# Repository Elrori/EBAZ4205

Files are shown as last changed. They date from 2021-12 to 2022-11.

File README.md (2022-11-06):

# EBAZ4205

EBIT EBAZ4205 ZYNQ7Z010 BOARD.

EBAZ4205是EBIT BTC矿机的控制板，是最便宜的矿板，其他还有EBAZ4203等。EBAZ4205板载一块Xilinx ZYNQ7Z010 SOC、256MB DDR3内存、一块128MB NAND和100M以太网PHY等。原理图和PCB从二手商获得。默认情况下，板子需要从2.0mm的PHD排针供电，电压5V-12V。Linux默认从NAND启动并执行挖矿控制程序。板子有SD卡接口，可以自己焊接SD卡接口，并更改电阻，使ZYNQ从SD启动。板子价格便宜适合用于学习ZYNQ。但是，比较遗憾的是ZYNQ的USB引脚并未引出。

- 裸机程序固化方法(原始板子)

  文章[链接](https://www.jianshu.com/p/b83c663ecaaa)

- u-boot&Linux生成方法记录(SD卡启动)

  文章[链接](https://www.jianshu.com/p/370f95f0068f)

- EBAZ4205+HDMI视频软解测试(SD卡启动)

  文章[链接](https://www.jianshu.com/p/f035751c2fe5)

- EBAZ420x OpenWrt Release.

  [Elrori/openwrt-auto](https://github.com/Elrori/openwrt-auto)
  
  [将EBAZ4205变为OpenWrt旁路由](https://blog.csdn.net/z951573431/article/details/123819564)

- 其他资料

  [其他关联repo(en)](https://github.com/xjtuecho/EBAZ4205)
  
  [EBIT S9原理图](https://github.com/openzynqhardware/ebaz4205-openwrt/tree/master/hardware/S9)

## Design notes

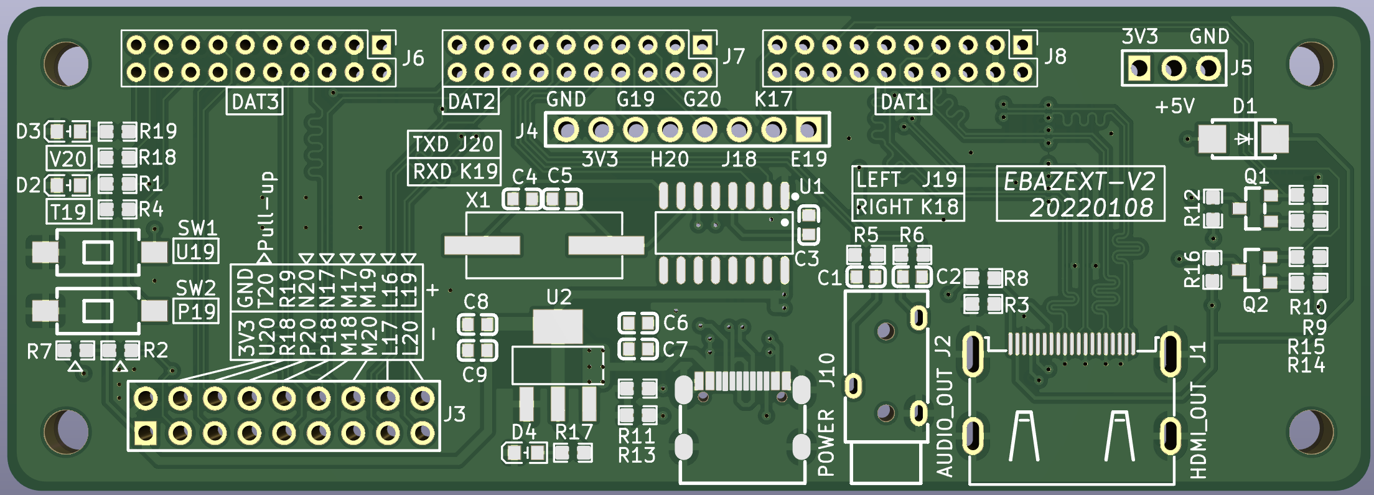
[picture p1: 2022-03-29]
EBAZEXT-V2/ebazext-v2.png

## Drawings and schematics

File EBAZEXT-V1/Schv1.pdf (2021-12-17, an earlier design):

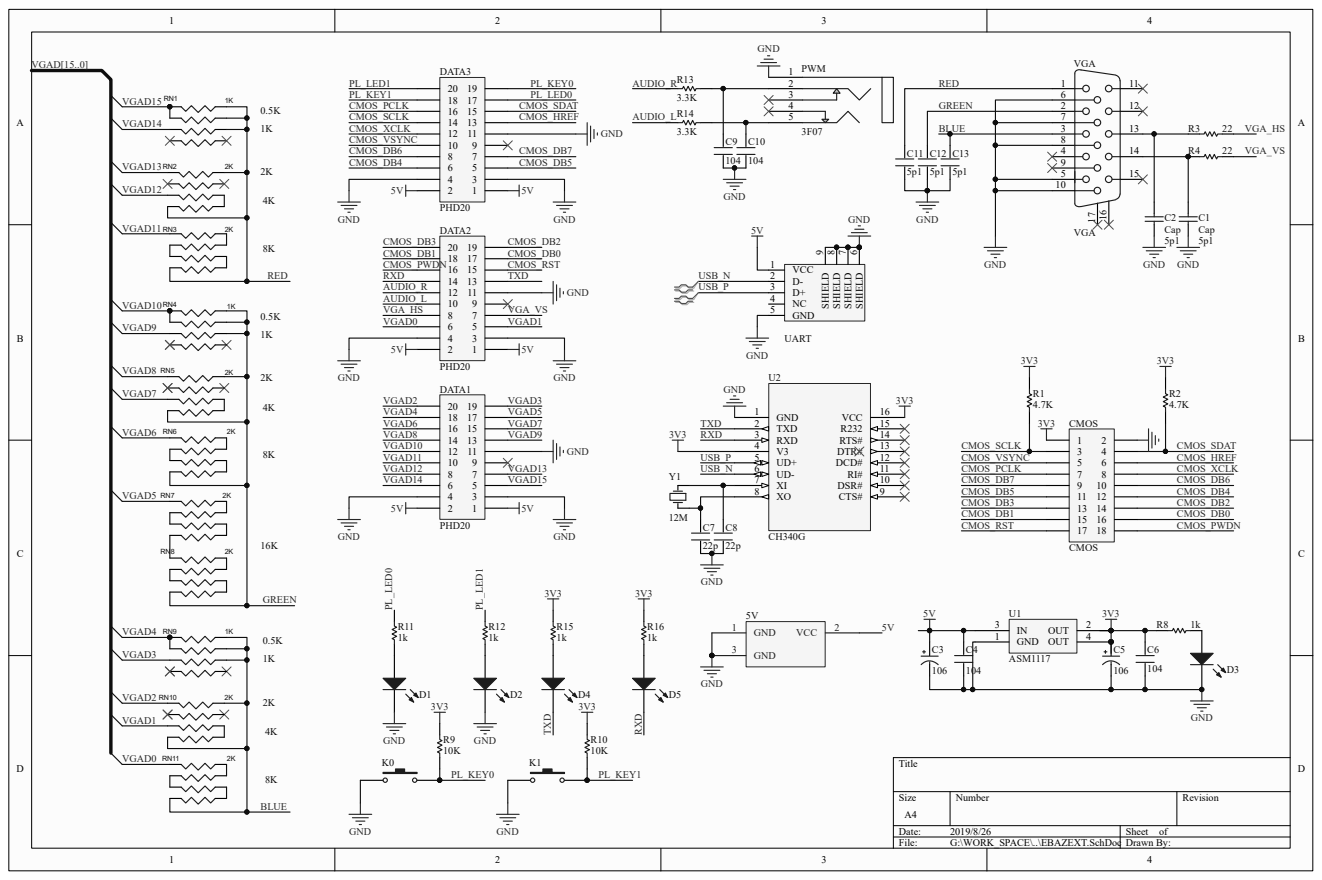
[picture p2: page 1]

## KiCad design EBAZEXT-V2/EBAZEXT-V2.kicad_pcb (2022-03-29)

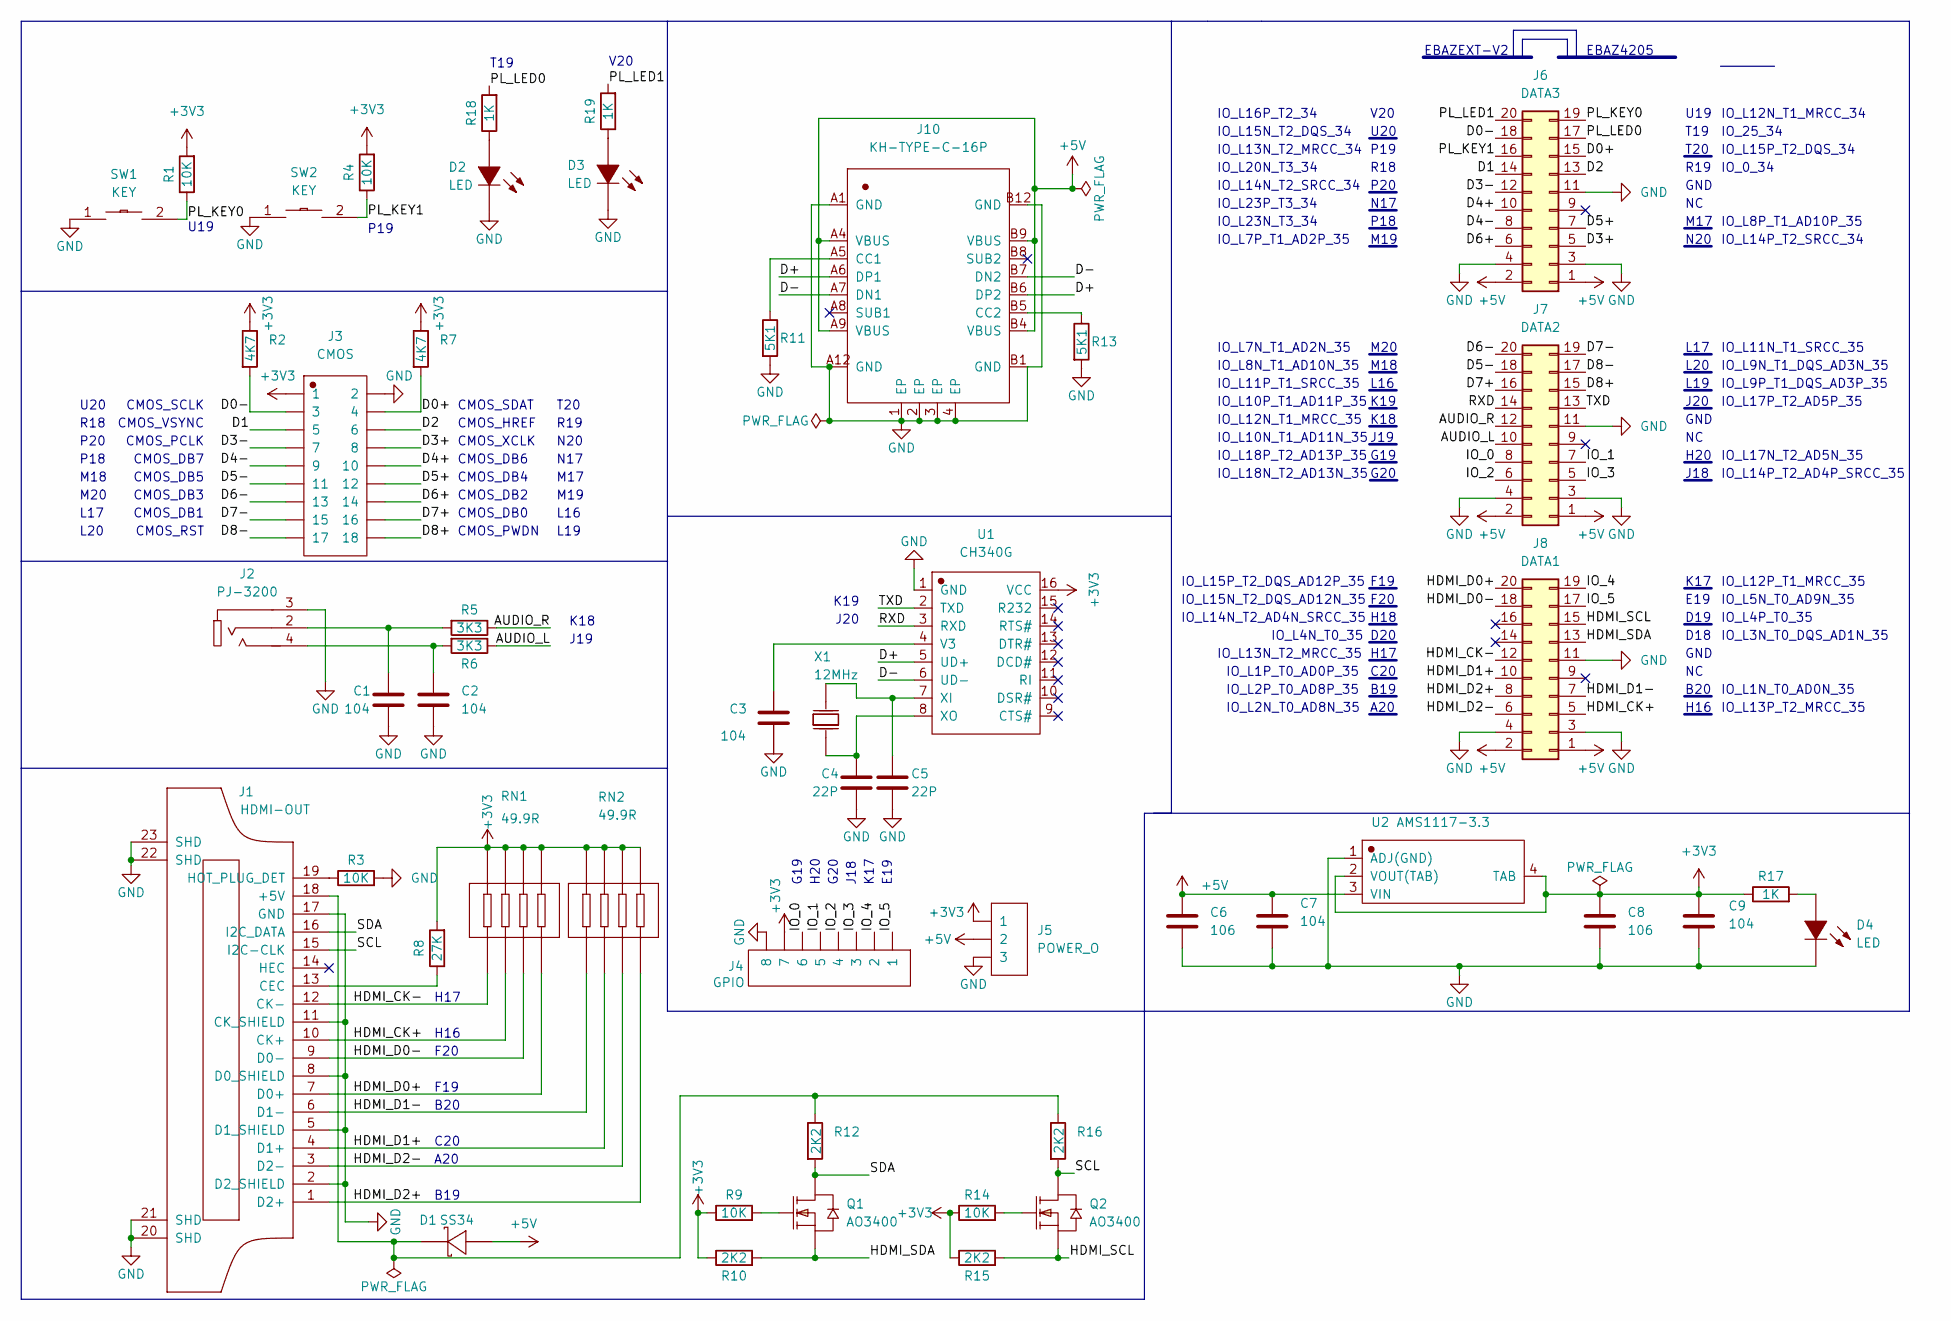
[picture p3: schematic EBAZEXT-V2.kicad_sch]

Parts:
C1, C2, C3, C7, C9: 104; C0603
C4, C5: 22P; C0603
C6, C8: 106; C0603
D1: SS34; DO-214AC_L4.3-W2.7-LS5.3-RD
D2, D3, D4: LED; LED0603-FD
J1: HDMI-OUT; HDMI-SMD_HDMI-019S
J2: PJ-3200; AUDIO-TH_PJ-3200
J3: CMOS; HDR-TH_18P-P2.54-V-F-R2-C9-S2.54-1
J4: GPIO; HDR-TH_8P-P2.54-V-F-1
J5: POWER_O; HDR-TH_3P-P2.54-V-M-1
J6: DATA3; EBAZEXT-DAT
J7: DATA2; EBAZEXT-DAT
J8: DATA1; EBAZEXT-DAT
J10: KH-TYPE-C-16P; USB-C-SMD_KH-TYPE-C-16P
Q1, Q2: AO3400; SOT-23_L2.9-W1.3-P1.90-LS2.4-BR
R1, R3, R4, R9, R14: 10K; R0603
R2, R7: 4K7; R0603
R5, R6: 3K3; R0603
R8: 27K; R0603
R10, R12, R15, R16: 2K2; R0603
R11, R13: 5K1; R0603
R17, R18, R19: 1K; R0603
RN1, RN2: 49.9R; RES-ARRAY-SMD_0603-8P-L3.2-W1.6-BL
SW1, SW2: KEY; SW-SMD_L6.0-W3.3-LS8.0
U1: CH340G; SOIC-16_L9.9-W3.9-P1.27-LS6.0-BL
U2: AMS1117-3.3; SOT-223-4_L6.5-W3.5-P2.30-LS7.0-BR
X1: 12MHz; HC-49S_L11.4-W4.8

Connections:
+3V3: C8.1, C9.1, J3.1, J4.7, J5.1, R1.2, R2.1, R4.2, R7.1, R8.2, R9.1, R10.1, R14.1, R15.1, R17.1, RN1.5, RN1.6, RN1.7, RN1.8, RN2.5, RN2.6, RN2.7, RN2.8, U1.16 (VCC), U2.2 (VOUT(TAB)), U2.4 (TAB)
+5V: C6.1, C7.1, D1.2 (A), J5.2, J6.1, J6.2, J7.1, J7.2, J8.1, J8.2, J10.A4 (VBUS), J10.A9 (VBUS), J10.B4 (VBUS), J10.B9 (VBUS), U2.3 (VIN)
/AUDIO_L: J7.10, R6.1
/AUDIO_R: J7.12, R5.1
/D0+: J3.4, J6.15, R7.2
/D0-: J3.3, J6.18, R2.2
/D1: J3.5, J6.14
/D2: J3.6, J6.13
/D3+: J3.8, J6.5
/D3-: J3.7, J6.12
/D4+: J3.10, J6.10
/D4-: J3.9, J6.8
/D5+: J3.12, J6.7
/D5-: J3.11, J7.18
/D6+: J3.14, J6.6
/D6-: J3.13, J7.20
/D7+: J3.16, J7.16
/D7-: J3.15, J7.19
/D8+: J3.18, J7.15
/D8-: J3.17, J7.17
/D+: J10.A6 (DP1), J10.B6 (DP2), U1.5 (UD+)
/D-: J10.A7 (DN1), J10.B7 (DN2), U1.6 (UD-)
/HDMI_CK+: J1.10 (CK+), J8.5, RN1.2
/HDMI_CK-: J1.12 (CK-), J8.12, RN1.1
/HDMI_D0+: J1.7 (D0+), J8.20, RN1.4
/HDMI_D0-: J1.9 (D0-), J8.18, RN1.3
/HDMI_D1+: J1.4 (D1+), J8.10, RN2.2
/HDMI_D1-: J1.6 (D1-), J8.7, RN2.1
/HDMI_D2+: J1.1 (D2+), J8.8, RN2.4
/HDMI_D2-: J1.3 (D2-), J8.6, RN2.3
/HDMI_SCL: J8.15, Q2.2 (S), R15.2
/HDMI_SDA: J8.13, Q1.2 (S), R10.2
/IO_0: J4.6, J7.8
/IO_1: J4.5, J7.7
/IO_2: J4.4, J7.6
/IO_3: J4.3, J7.5
/IO_4: J4.2, J8.19
/IO_5: J4.1, J8.17
/PL_KEY0: J6.19, R1.1, SW1.2
/PL_KEY1: J6.16, R4.1, SW2.2
/PL_LED0: J6.17, R18.2
/PL_LED1: J6.20, R19.2
/RXD: J7.14, U1.3 (RXD)
/SCL: J1.15 (I2C-CLK), Q2.3 (D), R16.2
/SDA: J1.16 (I2C_DATA), Q1.3 (D), R12.2
/TXD: J7.13, U1.2 (TXD)
GND: C1.2, C2.2, C3.2, C4.2, C5.2, C6.2, C7.2, C8.2, C9.2, D2.2 (K), D3.2 (K), D4.2 (K), J1.2 (D2_SHIELD), J1.5 (D1_SHIELD), J1.8 (D0_SHIELD), J1.11 (CK_SHIELD), J1.17 (GND), J1.20 (SHD), J1.21 (SHD), J1.22 (SHD), J1.23 (SHD), J2.3, J3.2, J4.8, J5.3, J6.3, J6.4, J6.11, J7.3, J7.4, J7.11, J8.3, J8.4, J8.11, J10.1 (EP), J10.2 (EP), J10.3 (EP), J10.4 (EP), J10.A1 (GND), J10.A12 (GND), J10.B1 (GND), J10.B12 (GND), R3.2, R11.2, R13.2, SW1.1, SW2.1, U1.1 (GND), U2.1 (ADJ(GND))
unnamed: C1.1, J2.2, R5.2
unnamed: C2.1, J2.4, R6.2
unnamed: C3.1, U1.4 (V3)
unnamed: C4.1, U1.8 (XO), X1.2 (OSC2)
unnamed: C5.1, U1.7 (XI), X1.1 (OSC1)
unnamed: D1.1 (K), J1.18 (+5V), R12.1, R16.1
unnamed: D2.1 (A), R18.1
unnamed: D3.1 (A), R19.1
unnamed: D4.1 (A), R17.2
unnamed: J1.13 (CEC), R8.1
unnamed: J1.19 (HOT_PLUG_DET), R3.1
unnamed: J10.A5 (CC1), R11.1
unnamed: J10.B5 (CC2), R13.1
unnamed: Q1.1 (G), R9.2
unnamed: Q2.1 (G), R14.2

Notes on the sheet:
IO_L17P_T2_AD5P_35
CMOS_DB4
IO_L2N_T0_AD8N_35
M18
M17
IO_L1P_T0_AD0P_35
M20
CMOS_SCLK
IO_L14P_T2_SRCC_34
IO_L11P_T1_SRCC_35
CMOS_XCLK
IO_0_34
IO_L1N_T0_AD0N_35
A20
F20
CMOS_DB1
K17
B20
IO_L9P_T1_DQS_AD3P_35
IO_L7N_T1_AD2N_35
L16
IO_L3N_T0_DQS_AD1N_35
R18
IO_L12N_T1_MRCC_34
IO_25_34
V20
H20
J19
IO_L18N_T2_AD13N_35
GND
N20
CMOS_DB2
L19
CMOS_PCLK
IO_L23P_T3_34
IO_L13N_T2_MRCC_35
T19
IO_L11N_T1_SRCC_35
IO_L5N_T0_AD9N_35
L17

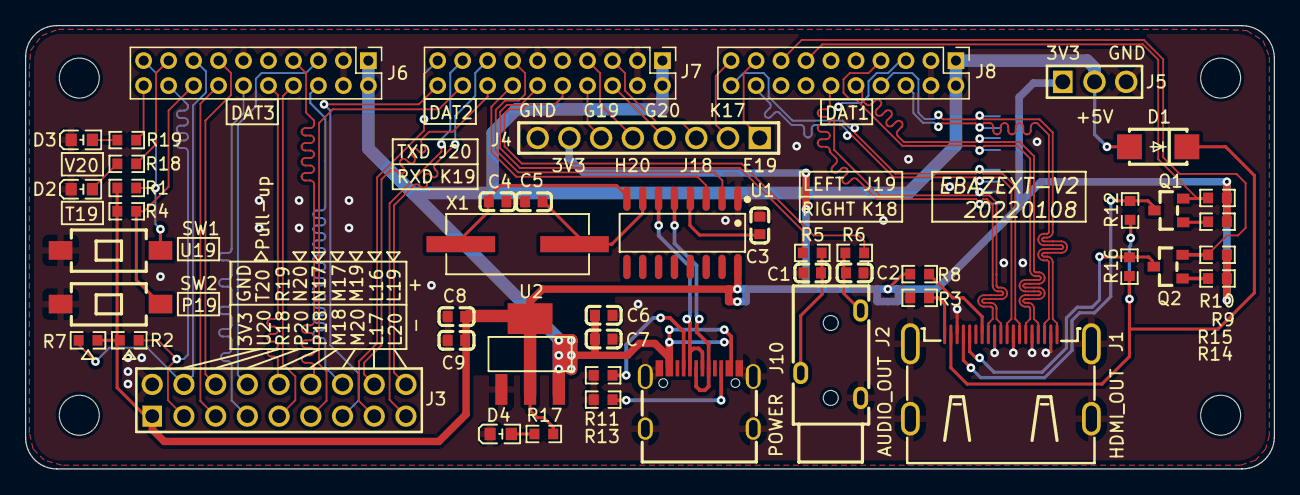
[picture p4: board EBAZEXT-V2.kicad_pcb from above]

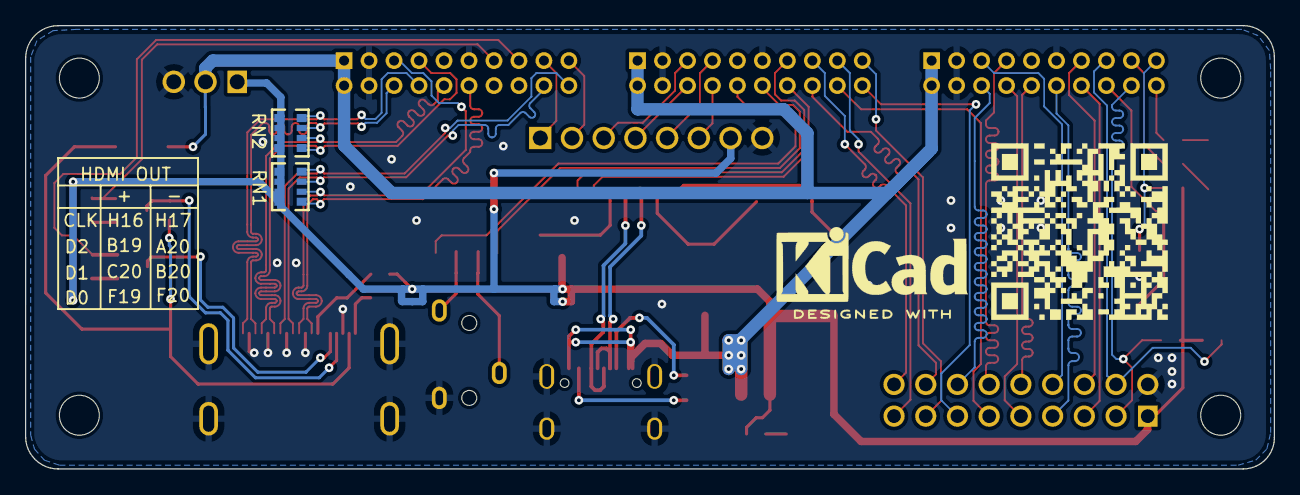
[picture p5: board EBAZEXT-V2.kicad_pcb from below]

Board: 2 copper layers, 100.0 x 35.5 mm, 52 parts (4 on the bottom side), 62 nets.

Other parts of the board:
G1: QRCode; LOGO
G2: KiCad-Logo2_6mm_SilkScreen

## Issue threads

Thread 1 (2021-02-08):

Expansion board

kasbert, 2021-02-08:
Please, would you upload the mentioned expansion board files to this repository ?
(https://programmersought.com/article/80046040945/  -> https://download.csdn.net/download/weixin_42157664/13073716 )
I am not able to download them.

Elrori, 2021-02-17:
Hi,

This download requires payment. I also made a VGA expansion board myself, which will be uploaded to the repo of ebaz4205

日常之夏,

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

kasbert, 2021-02-17:
I see. Thanks.

I am planning to make an expansion board with power, HDMI connector, camera header and a some PMOD headers, but I am an newbie with FPGAs and PCBs.

Closed 2021-02-17.

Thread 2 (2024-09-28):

There is an issue with the ch340G circuit schematic

Iamxiaosuan, 2024-09-28:
I encountered an issue where my computer was unable to recognize ch340G during the replication process。Some of the chips I use can recognize it, but the other batch cannot. I looked through the schematic of CH340G and found that when using a 3.3V power supply, pin 4 needs to be connected to a VCC. Which one did you refer to in your schematic? Why do some chips work despite being different from the official schematic

enoeric, 2024-09-28:
这是来自QQ邮箱的假期自动回复邮件。你好，邮件已收到，无法亲自回复你的邮件。看完后尽快给你回复。 谢谢

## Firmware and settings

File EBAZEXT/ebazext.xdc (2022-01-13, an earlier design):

########################################################################
### EBAZEXT pin
########################################################################
set_property PACKAGE_PIN T19 [get_ports {pl_led0}]
set_property IOSTANDARD LVCMOS33 [get_ports {pl_led0}]
set_property PACKAGE_PIN V20 [get_ports {pl_led1}]
set_property IOSTANDARD LVCMOS33 [get_ports {pl_led1}]
set_property PACKAGE_PIN U19 [get_ports {pl_key0}]
set_property IOSTANDARD LVCMOS33 [get_ports {pl_key0}]
set_property PACKAGE_PIN U20 [get_ports {pl_key1}]
set_property IOSTANDARD LVCMOS33 [get_ports {pl_key1}]

set_property PACKAGE_PIN P19 [get_ports {cmos_pclk}]
set_property IOSTANDARD LVCMOS33 [get_ports {cmos_pclk}]
set_property PACKAGE_PIN T20 [get_ports {cmos_sdat}]
set_property IOSTANDARD LVCMOS33 [get_ports {cmos_sdat}]
set_property PACKAGE_PIN R18 [get_ports {cmos_sclk}]
set_property IOSTANDARD LVCMOS33 [get_ports {cmos_sclk}]
set_property PACKAGE_PIN R19 [get_ports {cmos_href}]
set_property IOSTANDARD LVCMOS33 [get_ports {cmos_href}]
set_property PACKAGE_PIN P20 [get_ports {cmos_xclk}]
set_property IOSTANDARD LVCMOS33 [get_ports {cmos_xclk}]
set_property PACKAGE_PIN N17 [get_ports {cmos_vsync}]
set_property IOSTANDARD LVCMOS33 [get_ports {cmos_vsync}]
set_property PACKAGE_PIN L16 [get_ports {cmos_pwdn}]
set_property IOSTANDARD LVCMOS33 [get_ports {cmos_pwdn}]
set_property PACKAGE_PIN L19 [get_ports {cmos_rst}]
set_property IOSTANDARD LVCMOS33 [get_ports {cmos_rst}]
set_property PACKAGE_PIN M17 [get_ports {cmos_db[7]}]
set_property IOSTANDARD LVCMOS33 [get_ports {cmos_db[7]}]
set_property PACKAGE_PIN P18 [get_ports {cmos_db[6]}]
set_property IOSTANDARD LVCMOS33 [get_ports {cmos_db[6]}]
set_property PACKAGE_PIN N20 [get_ports {cmos_db[5]}]
set_property IOSTANDARD LVCMOS33 [get_ports {cmos_db[5]}]
set_property PACKAGE_PIN M19 [get_ports {cmos_db[4]}]
set_property IOSTANDARD LVCMOS33 [get_ports {cmos_db[4]}]
set_property PACKAGE_PIN M20 [get_ports {cmos_db[3]}]
set_property IOSTANDARD LVCMOS33 [get_ports {cmos_db[3]}]
set_property PACKAGE_PIN L17 [get_ports {cmos_db[2]}]
set_property IOSTANDARD LVCMOS33 [get_ports {cmos_db[2]}]
set_property PACKAGE_PIN M18 [get_ports {cmos_db[1]}]
set_property IOSTANDARD LVCMOS33 [get_ports {cmos_db[1]}]
set_property PACKAGE_PIN L20 [get_ports {cmos_db[0]}]
set_property IOSTANDARD LVCMOS33 [get_ports {cmos_db[0]}]

set_property PACKAGE_PIN K19 [get_ports {rxd}]
set_property IOSTANDARD LVCMOS33 [get_ports {rxd}]
set_property PACKAGE_PIN J20 [get_ports {txd}]
set_property IOSTANDARD LVCMOS33 [get_ports {txd}]

set_property PACKAGE_PIN K18 [get_ports {audio_r}]
set_property IOSTANDARD LVCMOS33 [get_ports {audio_r}]
set_property PACKAGE_PIN J19 [get_ports {audio_l}]
set_property IOSTANDARD LVCMOS33 [get_ports {audio_l}]

set_property PACKAGE_PIN G19 [get_ports {vga_hs}]
set_property IOSTANDARD LVCMOS33 [get_ports {vga_hs}]
set_property PACKAGE_PIN H20 [get_ports {vga_vs}]
set_property IOSTANDARD LVCMOS33 [get_ports {vga_vs}]
set_property PACKAGE_PIN G20 [get_ports {vgad[0]}]
set_property IOSTANDARD LVCMOS33 [get_ports {vgad[0]}]
set_property PACKAGE_PIN J18 [get_ports {vgad[1]}]
set_property IOSTANDARD LVCMOS33 [get_ports {vgad[1]}]
set_property PACKAGE_PIN F19 [get_ports {vgad[2]}]
set_property IOSTANDARD LVCMOS33 [get_ports {vgad[2]}]
set_property PACKAGE_PIN K17 [get_ports {vgad[3]}]
set_property IOSTANDARD LVCMOS33 [get_ports {vgad[3]}]
set_property PACKAGE_PIN F20 [get_ports {vgad[4]}]
set_property IOSTANDARD LVCMOS33 [get_ports {vgad[4]}]
set_property PACKAGE_PIN E19 [get_ports {vgad[5]}]
set_property IOSTANDARD LVCMOS33 [get_ports {vgad[5]}]
set_property PACKAGE_PIN H18 [get_ports {vgad[6]}]
set_property IOSTANDARD LVCMOS33 [get_ports {vgad[6]}]
set_property PACKAGE_PIN D19 [get_ports {vgad[7]}]
set_property IOSTANDARD LVCMOS33 [get_ports {vgad[7]}]
set_property PACKAGE_PIN D20 [get_ports {vgad[8]}]
set_property IOSTANDARD LVCMOS33 [get_ports {vgad[8]}]
set_property PACKAGE_PIN D18 [get_ports {vgad[9]}]
set_property IOSTANDARD LVCMOS33 [get_ports {vgad[9]}]
set_property PACKAGE_PIN H17 [get_ports {vgad[10]}]
set_property IOSTANDARD LVCMOS33 [get_ports {vgad[10]}]
set_property PACKAGE_PIN C20 [get_ports {vgad[11]}]
set_property IOSTANDARD LVCMOS33 [get_ports {vgad[11]}]
set_property PACKAGE_PIN B19 [get_ports {vgad[12]}]
set_property IOSTANDARD LVCMOS33 [get_ports {vgad[12]}]
set_property PACKAGE_PIN B20 [get_ports {vgad[13]}]
set_property IOSTANDARD LVCMOS33 [get_ports {vgad[13]}]
set_property PACKAGE_PIN A20 [get_ports {vgad[14]}]
set_property IOSTANDARD LVCMOS33 [get_ports {vgad[14]}]
set_property PACKAGE_PIN H16 [get_ports {vgad[15]}]
set_property IOSTANDARD LVCMOS33 [get_ports {vgad[15]}]
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

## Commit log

2021-12-17 vga external board
    [EBAZEXT.PcbDoc, EBAZEXT.SchDoc]
2022-01-13 vga expansion
    [EBAZEXTV1.PcbDoc, EBAZEXTV1.SchDoc]
2022-03-29 add EBAZEXT-V2
    [EBAZEXT-V2.kicad_pcb, EBAZEXT-V2.kicad_sch, EBAZEXTV1.PcbDoc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]
